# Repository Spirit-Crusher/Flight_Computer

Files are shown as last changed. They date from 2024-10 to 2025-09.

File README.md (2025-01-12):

MCU: https://www.microchip.com/en-us/product/pic32mz2048efh100

GPS: https://pt.mouser.com/ProductDetail/u-blox/NEO-M8J?qs=sGAEpiMZZMu3sxpa5v1qrlhWywTP0pnuh%2BmP8LamgMg%3D

Data logging for GPS: https://pt.mouser.com/ProductDetail/Microchip-Technology/SST26VF032BT-104I-SM?qs=wzzOUr4NhYqzScXXOX3HBA%3D%3D

IMU (acel + gyro): https://pt.mouser.com/ProductDetail/STMicroelectronics/LSM6DS3TR-C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

Magnetómetro: https://pt.mouser.com/ProductDetail/STMicroelectronics/LIS3MDLTR?qs=hnsWAVXnr6EbLE48dGN9Pg%3D%3D

Altímetro (temp incluída): https://pt.mouser.com/ProductDetail/Measurement-Specialties/MS560702BA03-50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

Buzzer: https://www.digikey.com/en/products/detail/ole-wolff-electronics-inc/OWMB-858540SA-40-15/16735155

Antena(GPS): ???

Telemetry transmiter/antenna: ???

Data logging (flash memory IC): https://pt.mouser.com/ProductDetail/Winbond/W25Q128JVSIQ?qs=qSfuJ%252Bfl%2Fd6tLXvPR4fl9w%3D%3D

Power management IC: https://pt.mouser.com/ProductDetail/Texas-Instruments/INA219BIDR?qs=1WmUhT%2FVMINyGsXNJcdD5Q%3D%3D (maybe BMS board would be better)

Pyro channels and others

Ver redundância 

# DONE
- [x] Decoupling capacitors for each IC and basic conections.
- [ ] Sorting out power (all 3V3 or anything else needed?)
- [ ] Reverse polarity protection (which approach should I use?)
- [x] Programmer pins connector

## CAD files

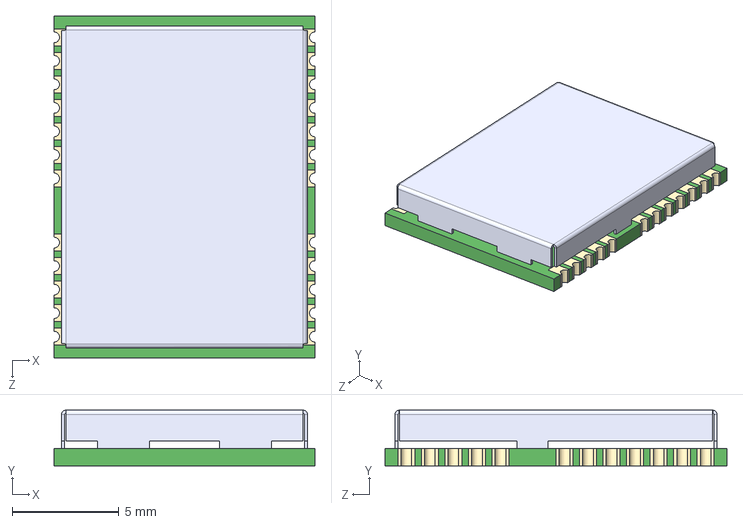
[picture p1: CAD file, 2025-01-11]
GPS_NEO-M8J/NEO-M8Q/NEO-8Q-0.STEP
12.2 x 2.60 x 16.0 mm

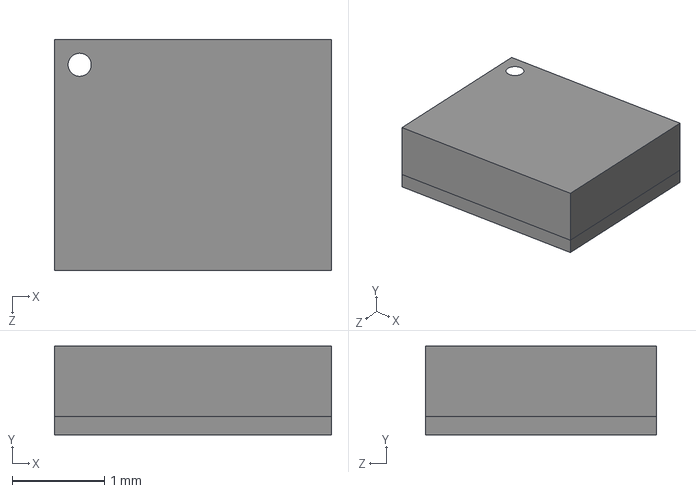
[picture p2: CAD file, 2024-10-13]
IMU_LSM6DS3TR-C/LSM6DS3TR-C.step
3.00 x 0.96 x 2.50 mm

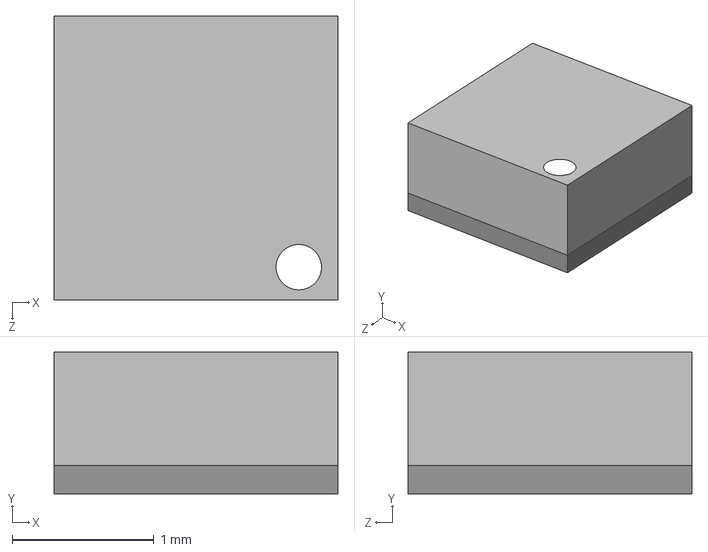
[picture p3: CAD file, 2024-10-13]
MAG_LIS3MDLTR/LIS3MDLTR.step
2.00 x 1.00 x 2.00 mm

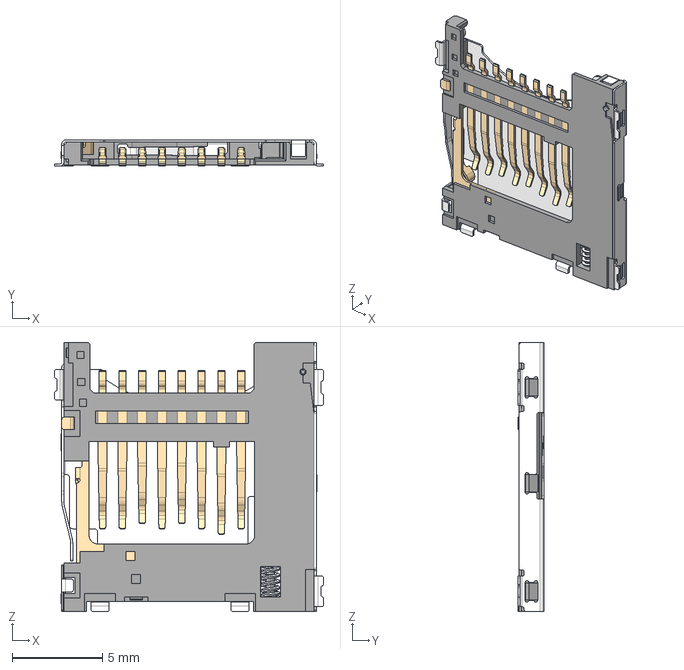
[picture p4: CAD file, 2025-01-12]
MICRO_SD/MEM2090-00-145-00-A_REVA/MEM2090-00-145-00-A_REVA.step
14.9 x 1.45 x 15.0 mm

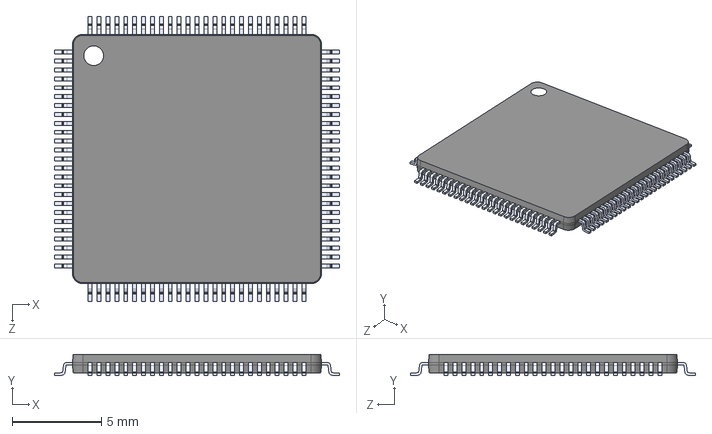
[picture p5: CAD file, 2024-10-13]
PIC32MZ2048EFH100-E_PF/PIC32MZ2048EFH100-E_PF.step
16.0 x 1.20 x 16.0 mm

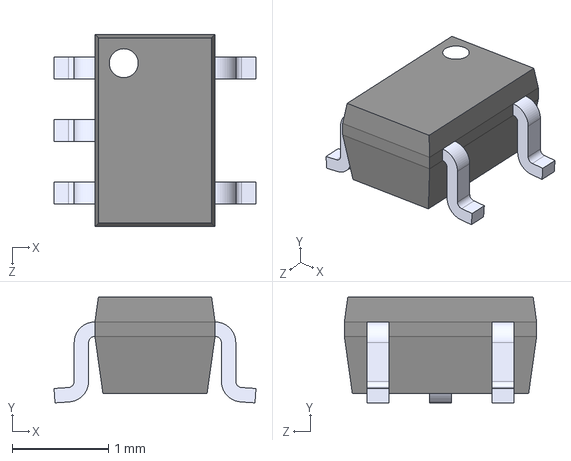
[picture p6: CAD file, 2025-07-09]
SN74AHCT1G125DCKR level shifter/SN74AHCT1G125DCKR.step
2.10 x 1.10 x 2.00 mm

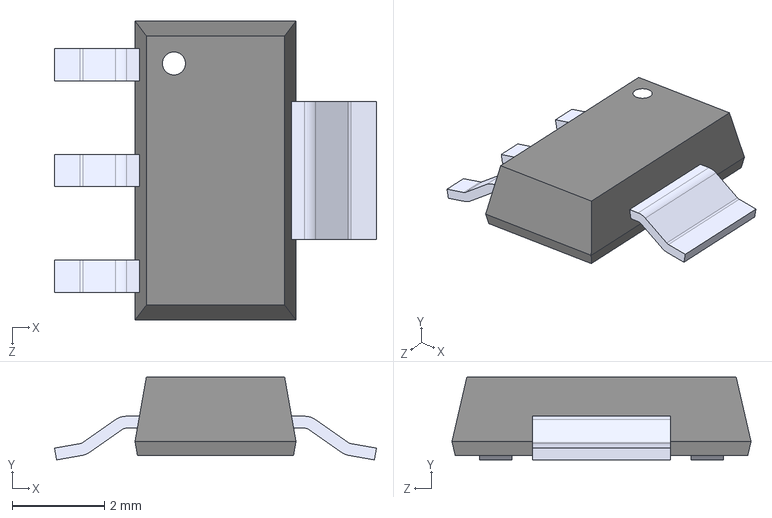
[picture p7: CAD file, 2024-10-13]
Voltage regulation/LDL1117S33R/LDL1117S33R.step
7.00 x 1.80 x 6.50 mm

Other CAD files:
Voltage regulation/LM7805MPX_NOPB/LM7805MPX_NOPB.step

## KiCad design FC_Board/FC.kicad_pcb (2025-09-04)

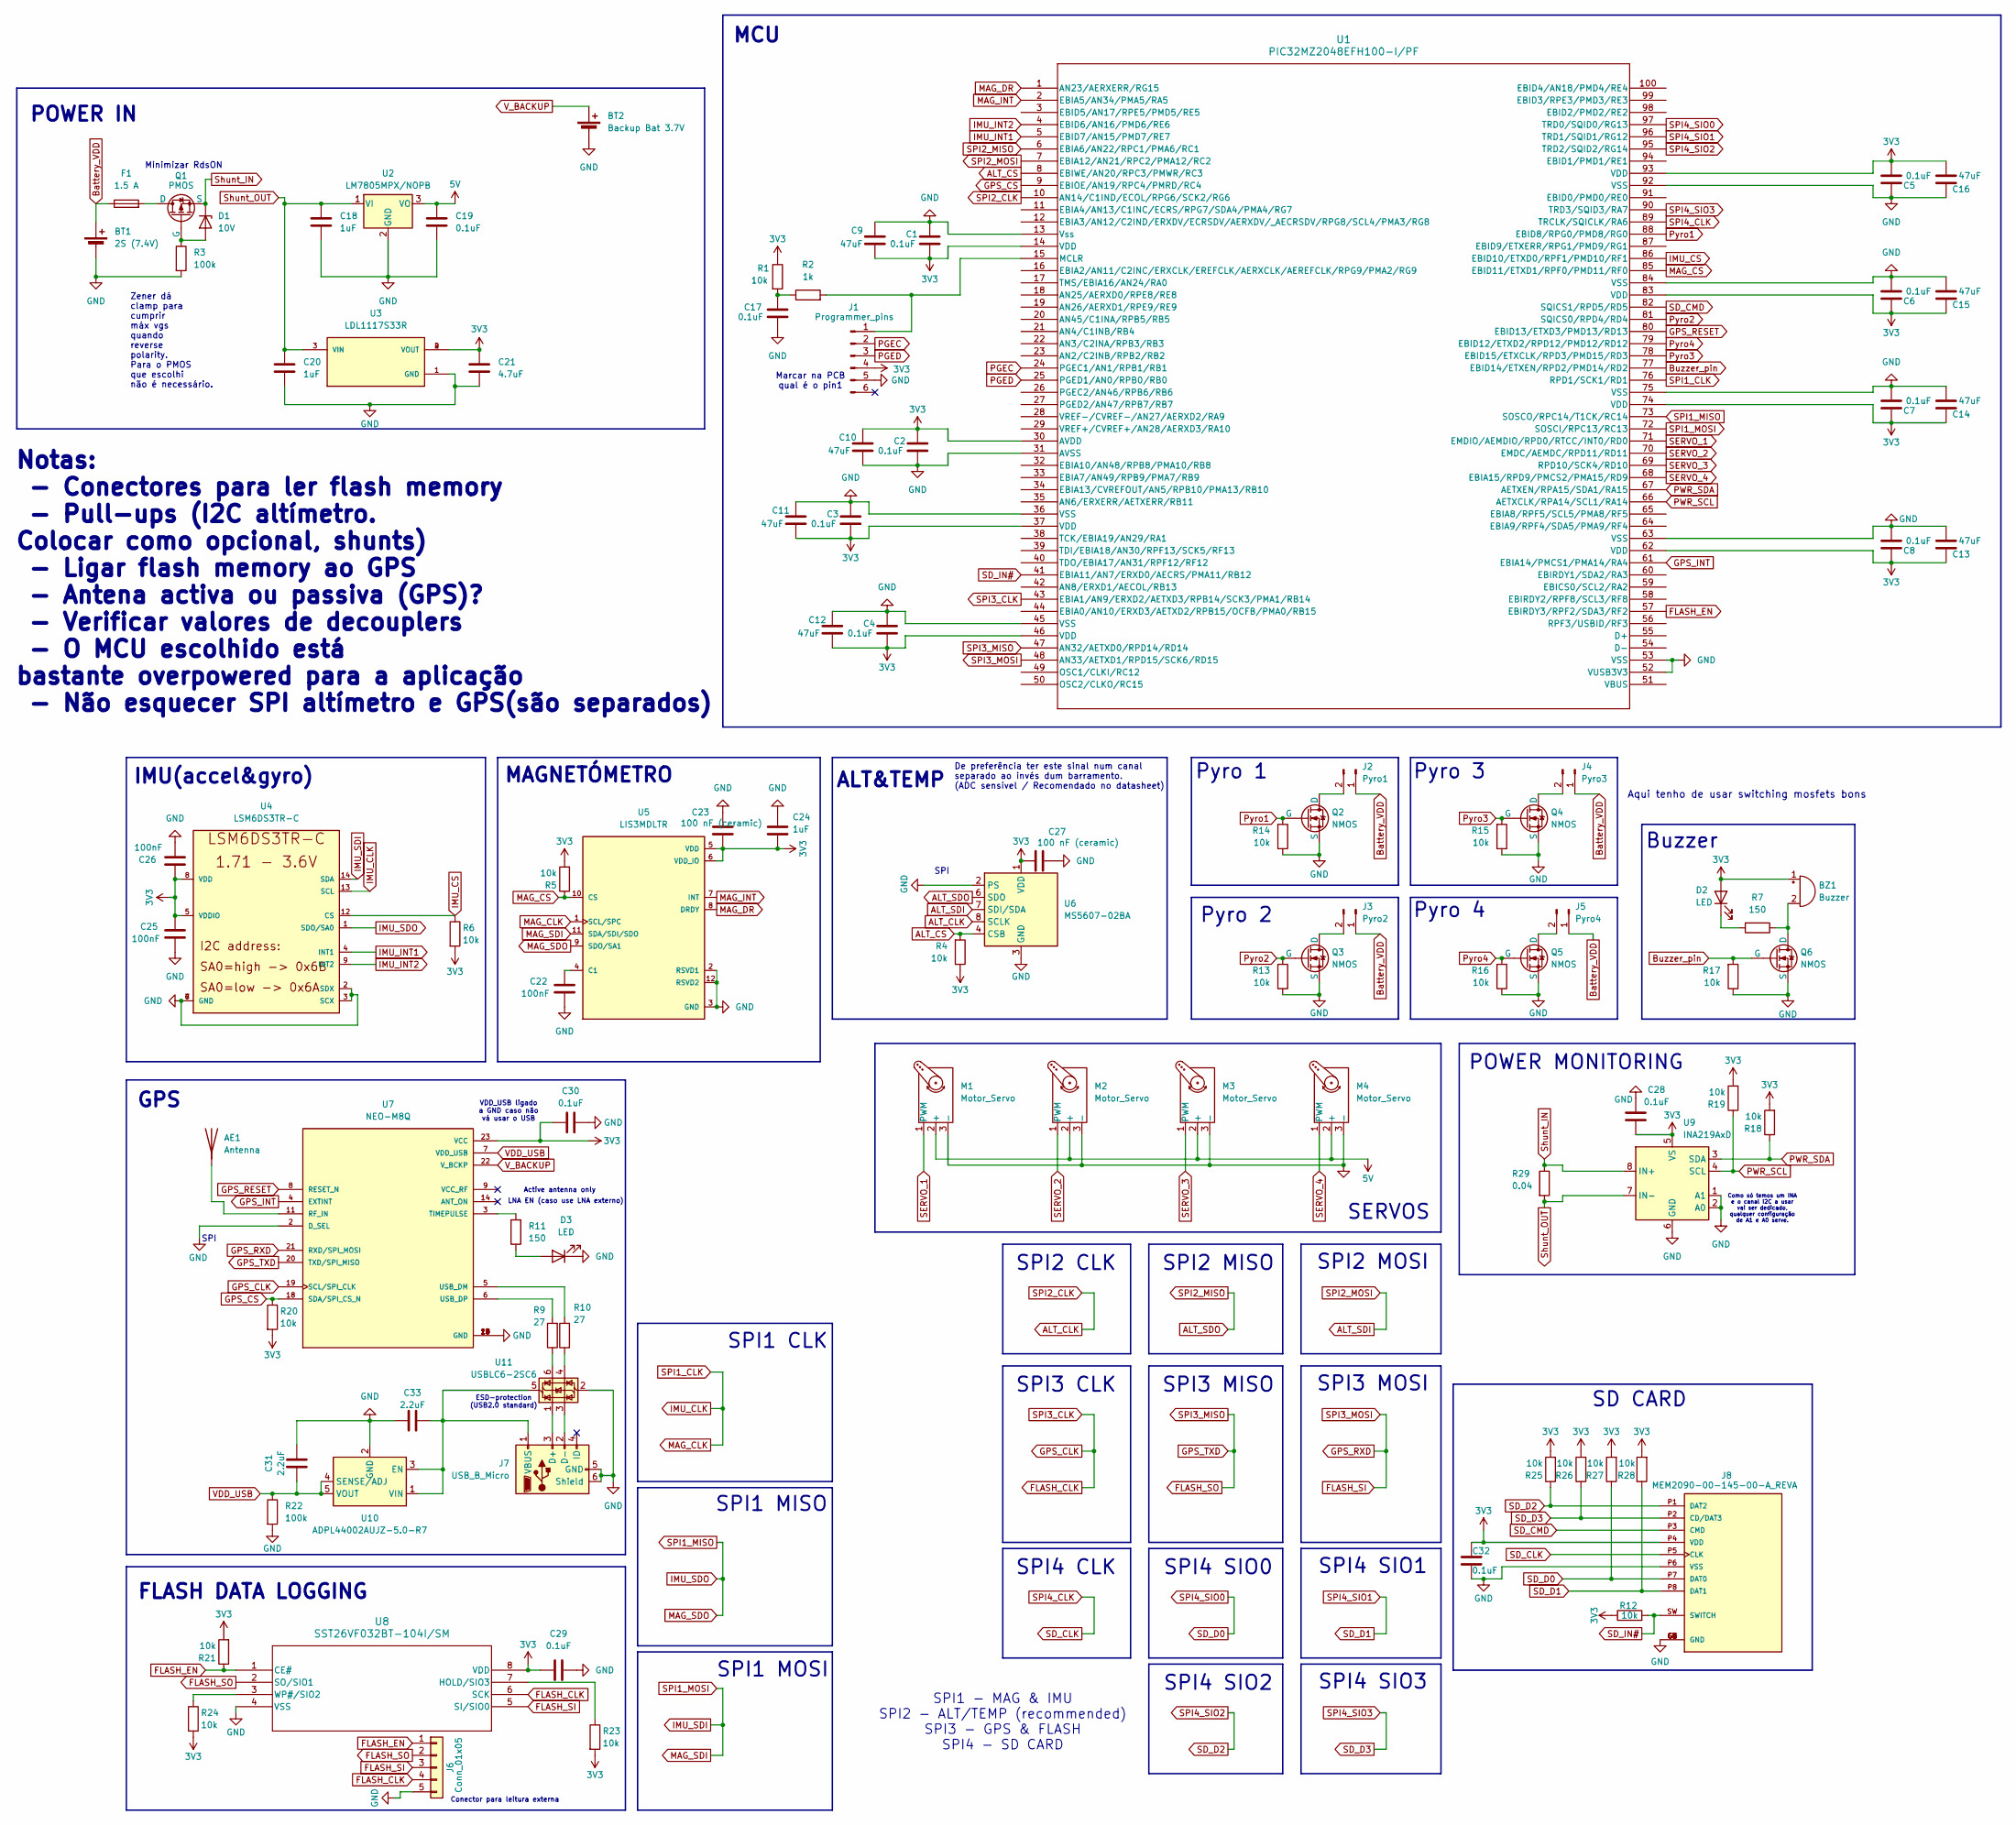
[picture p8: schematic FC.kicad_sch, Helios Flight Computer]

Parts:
AE1: Antenna; SMA_Samtec_SMA-J-P-H-ST-EM1_EdgeMount
BT1: 2S (7.4V); AMASS_XT60-M_1x02_P7.20mm_Vertical
BT2: Backup Bat 3.7V; JST_EH_B2B-EH-A_1x02_P2.50mm_Vertical
BZ1: Buzzer; Buzzer_12x9.5RM7.6
C1, C2, C3, C4, C5, C6, C7, C8, C17, C19, C28, C29, C30, C32: 0.1uF; C_0603_1608Metric_Pad1.08x0.95mm_HandSolder
C9, C10, C11, C12, C13, C14, C15, C16: 47uF; C_1210_3225Metric_Pad1.33x2.70mm_HandSolder
C18, C20, C24: 1uF; C_0603_1608Metric_Pad1.08x0.95mm_HandSolder
C21: 4.7uF; C_0805_2012Metric_Pad1.18x1.45mm_HandSolder
C22, C25, C26: 100nF; C_0603_1608Metric_Pad1.08x0.95mm_HandSolder
C23, C27: 100 nF (ceramic); C_0603_1608Metric_Pad1.08x0.95mm_HandSolder
C31, C33: 2.2uF; C_0603_1608Metric_Pad1.08x0.95mm_HandSolder
D1: 10V; D_SOD-323_HandSoldering
D2, D3: LED; LED_D3.0mm
F1: 1.5 A; Fuseholder_Cylinder-5x20mm_Schurter_0031_8201_Horizontal_Op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
J1: Programmer_pins; PinHeader_1x06_P2.54mm_Horizontal
J2: Pyro1; Molex_KK-254_AE-6410-02A_1x02_P2.54mm_Vertical
J3: Pyro2; Molex_KK-254_AE-6410-02A_1x02_P2.54mm_Vertical
J4: Pyro3; Molex_KK-254_AE-6410-02A_1x02_P2.54mm_Vertical
J5: Pyro4; Molex_KK-254_AE-6410-02A_1x02_P2.54mm_Vertical
J6: Conn_01x05; PinHeader_1x05_P2.54mm_Vertical
J7: USB_B_Micro; USB_Micro-B_Molex-105017-0001
J8: MEM2090-00-145-00-A_REVA; GCT_MEM2090-00-145-00-A_REVA; PARTREV A
M1, M2, M3, M4: Motor_Servo; Molex_KK-254_AE-6410-03A_1x03_P2.54mm_Vertical
Q1: PMOS; SOT-23-3
Q2, Q3, Q4, Q5, Q6: NMOS; SOT-23
R1, R4, R5, R6, R12, R13, R14, R15, R16, R17, R18, R19, R20, R21, R23, R24, R25, R26, R27, R28: 10k; R_0805_2012Metric_Pad1.20x1.40mm_HandSolder
R2: 1k; R_0805_2012Metric_Pad1.20x1.40mm_HandSolder
R3, R22: 100k; R_1206_3216Metric_Pad1.30x1.75mm_HandSolder
R7, R11: 150; R_0603_1608Metric_Pad0.98x0.95mm_HandSolder
R9, R10: 27; R_0603_1608Metric_Pad0.98x0.95mm_HandSolder
R29: 0.04; R_2512_6332Metric_Pad1.40x3.35mm_HandSolder
U1: PIC32MZ2048EFH100-I/PF; QFP50P1600X1600X120-100N
U2: LM7805MPX/NOPB; TO-220-3_Vertical
U3: LDL1117S33R; SOT230P700X180-4N; PARTREV 7
U4: LSM6DS3TR-C; LGA-14-2.5X3MM
U5: LIS3MDLTR; XDCR_LIS3MDLTR; PARTREV 6
U6: MS5607-02BA; LGA-8_3x5mm_P1.25mm
U7: NEO-M8Q; XCVR_NEO-M8Q; PARTREV 10
U8: SST26VF032BT-104I/SM; SOIC-8W_5.3x5.3mm_P1.27mm
U9: INA219AxD; SOIC-8_3.9x4.9mm_P1.27mm
U10: ADPL44002AUJZ-5.0-R7; TSOT-23-5
U11: USBLC6-2SC6; SOT-23-6

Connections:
3V3: BZ1.1 (+), C1.2, C2.1, C3.2, C4.2, C5.2, C6.1, C7.1, C8.1, C9.2, C10.1, C11.2, C12.2, C13.1, C14.1, C15.1, C16.2, C21.1, C23.2, C24.2, C25.1, C26.1, C27.2, C28.1, C29.2, C30.2, C32.1, D2.2 (A), J1.4, J8.P4 (VDD), R1.1, R4.1, R5.2, R6.2, R12.1, R18.2, R19.2, R20.2, R21.2, R23.2, R24.2, R25.2, R26.2, R27.2, R28.2, U1.14 (VDD), U1.30 (AVDD), U1.37 (VDD), U1.46 (VDD), U1.62 (VDD), U1.74 (VDD), U1.83 (VDD), U1.93 (VDD), U3.2 (VOUT), U3.4 (VOUT), U4.5 (VDDIO), U4.8 (VDD), U5.5 (VDD), U5.6 (VDD_IO), U6.1 (VDD), U7.23 (VCC), U8.8 (VDD), U9.5 (VS)
5V: C19.1, M1.2 (+), M2.2 (+), M3.2 (+), M4.2 (+), U2.3 (VO)
ALT_CLK: U1.10 (AN14/C1IND/ECOL/RPG6/SCK2/RG6), U6.8 (SCLK)
ALT_CS: R4.2, U1.8 (EBIWE/AN20/RPC3/PMWR/RC3), U6.4 (CSB), U6.5 (CSB)
ALT_SDI: U1.7 (EBIA12/AN21/RPC2/PMA12/RC2), U6.7 (SDI/SDA)
ALT_SDO: U1.6 (EBIA6/AN22/RPC1/PMA6/RC1), U6.6 (SDO)
Battery_VDD: BT1.1 (+), F1.1, J2.1, J3.1, J4.1, J5.1
Buzzer_pin: Q6.2 (G), R17.2, U1.77 (EBID14/ETXEN/RPD2/PMD14/RD2)
FLASH_CLK: J6.4, U1.43 (EBIA1/AN9/ERXD2/AETXD3/RPB14/SCK3/PMA1/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), U7.19 (SCL/SPI_CLK), U8.6 (SCK)
FLASH_EN: J6.1, R21.1, U1.57 (EBIRDY3/RPF2/SDA3/RF2), U8.1 (CE#)
FLASH_SI: J6.3, U1.48 (AN33/AETXD1/RPD15/SCK6/RD15), U7.21 (RXD/SPI_MOSI), U8.5 (SI/SIO0)
FLASH_SO: J6.2, U1.47 (AN32/AETXD0/RPD14/RD14), U7.20 (TXD/SPI_MISO), U8.2 (SO/SIO1)
GND: BT1.2 (-), BT2.2 (-), C1.1, C2.2, C3.1, C4.1, C5.1, C6.2, C7.2, C8.2, C9.1, C10.2, C11.1, C12.1, C13.2, C14.2, C15.2, C16.1, C17.2, C18.2, C19.2, C20.2, C21.2, C22.2, C23.1, C24.1, C25.2, C26.2, C27.1, C28.2, C29.1, C30.1, C31.2, C32.2, C33.1, D3.1 (K), J1.5, J6.5, J7.5 (GND), J7.6 (Shield), J8.G1 (GND), J8.G2 (GND), J8.G3 (GND), J8.G4 (GND), J8.G5 (GND), J8.G6 (GND), J8.P6 (VSS), M1.3 (-), M2.3 (-), M3.3 (-), M4.3 (-), Q2.3 (S), Q3.3 (S), Q4.3 (S), Q5.3 (S), Q6.3 (S), R3.2, R13.1, R14.1, R15.1, R16.1, R17.1, R22.2, U1.13 (Vss), U1.31 (AVSS), U1.36 (VSS), U1.45 (VSS), U1.52 (VUSB3V3), U1.53 (VSS), U1.63 (VSS), U1.75 (VSS), U1.84 (VSS), U1.92 (VSS), U2.2 (GND), U3.1 (GND), U4.2 (SDX), U4.3 (SCX), U4.6 (GND), U4.7 (GND), U5.2 (RSVD1), U5.3 (GND), U5.12 (RSVD2), U6.2 (PS), U6.3 (GND), U7.2 (D_SEL), U7.10 (GND), U7.12 (GND), U7.13 (GND), U7.24 (GND), U8.4 (VSS), U9.1 (A1), U9.2 (A0), U9.6 (GND), U10.2 (GND), U11.2 (GND)
GPS_CS: R20.1, U1.9 (EBIOE/AN19/RPC4/PMRD/RC4), U7.18 (SDA/SPI_CS_N)
GPS_INT: U1.61 (EBIA14/PMCS1/PMA14/RA4), U7.4 (EXTINT)
GPS_RESET: U1.80 (EBID13/ETXD3/PMD13/RD13), U7.8 (RESET_N)
IMU_CLK: U1.76 (RPD1/SCK1/RD1), U4.13 (SCL), U5.1 (SCL/SPC)
IMU_CS: R6.1, U1.86 (EBID10/ETXD0/RPF1/PMD10/RF1), U4.12 (CS)
IMU_INT1: U1.5 (EBID7/AN15/PMD7/RE7), U4.4 (INT1)
IMU_INT2: U1.4 (EBID6/AN16/PMD6/RE6), U4.9 (INT2)
IMU_SDI: U1.72 (SOSCI/RPC13/RC13), U4.14 (SDA), U5.11 (SDA/SDI/SDO)
IMU_SDO: U1.73 (SOSCO/RPC14/T1CK/RC14), U4.1 (SDO/SA0), U5.9 (SDO/SA1)
MAG_CS: R5.1, U1.85 (EBID11/ETXD1/RPF0/PMD11/RF0), U5.10 (CS)
MAG_DR: U1.1 (AN23/AERXERR/RG15), U5.8 (DRDY)
MAG_INT: U1.2 (EBIA5/AN34/PMA5/RA5), U5.7 (INT)
unnamed: AE1.1 (A), U7.11 (RF_IN)
unnamed: BZ1.2 (-), Q6.1 (D), R7.1
unnamed: C17.1, R1.2, R2.1
unnamed: D1.2 (A), Q1.2 (G), R3.1
unnamed: D2.1 (K), R7.2
unnamed: D3.2 (A), R11.1
unnamed: J1.1, R2.2, U1.15 (MCLR)
unnamed: J2.2, Q2.1 (D)
unnamed: J3.2, Q3.1 (D)
unnamed: J4.2, Q4.1 (D)
unnamed: J5.2, Q5.1 (D)
unnamed: J7.3 (D+), U11.1 (I/O1)
unnamed: J7.2 (D-), U11.3 (I/O2)
unnamed: C33.2, J7.1 (VBUS), U10.1 (VIN), U10.3 (EN), U11.5 (VBUS)
unnamed: F1.2, Q1.1 (D)
unnamed: R9.1, U11.6 (I/O1)
unnamed: R10.1, U11.4 (I/O2)
unnamed: C22.1, U5.4 (C1)
unnamed: R11.2, U7.3 (TIMEPULSE)
unnamed: R10.2, U7.5 (USB_DM)
unnamed: R9.2, U7.6 (USB_DP)
unnamed: R23.1, U8.7 (HOLD/SIO3)
unnamed: R24.1, U8.3 (WP#/SIO2)
PGEC: J1.2, U1.24 (PGEC1/AN1/RPB1/RB1)
PGED: J1.3, U1.25 (PGED1/AN0/RPB0/RB0)
PWR_SCL: R19.1, U1.66 (AETXCLK/RPA14/SCL1/RA14), U9.4 (SCL)
PWR_SDA: R18.1, U1.67 (AETXEN/RPA15/SDA1/RA15), U9.3 (SDA)
Pyro1: Q2.2 (G), R14.2, U1.88 (EBID8/RPG0/PMD8/RG0)
Pyro2: Q3.2 (G), R13.2, U1.81 (SQICS0/RPD4/RD4)
Pyro3: Q4.2 (G), R15.2, U1.78 (EBID15/ETXCLK/RPD3/PMD15/RD3)
Pyro4: Q5.2 (G), R16.2, U1.79 (EBID12/ETXD2/RPD12/PMD12/RD12)
SD_CLK: J8.P5 (CLK), U1.89 (TRCLK/SQICLK/RA6)
SD_CMD: J8.P3 (CMD), U1.82 (SQICS1/RPD5/RD5)
SD_D0: J8.P7 (DAT0), R27.1, U1.97 (TRD0/SQID0/RG13)
SD_D1: J8.P8 (DAT1), R28.1, U1.96 (TRD1/SQID1/RG12)
SD_D2: J8.P1 (DAT2), R25.1, U1.95 (TRD2/SQID2/RG14)
SD_D3: J8.P2 (CD/DAT3), R26.1, U1.90 (TRD3/SQID3/RA7)
SD_IN#: J8.SW (SWITCH), R12.2, U1.41 (EBIA11/AN7/ERXD0/AECRS/PMA11/RB12)
SERVO_1: M1.1 (PWM), U1.71 (EMDIO/AEMDIO/RPD0/RTCC/INT0/RD0)
SERVO_2: M2.1 (PWM), U1.70 (EMDC/AEMDC/RPD11/RD11)
SERVO_3: M3.1 (PWM), U1.69 (RPD10/SCK4/RD10)
SERVO_4: M4.1 (PWM), U1.68 (EBIA15/RPD9/PMCS2/PMA15/RD9)
Shunt_IN: D1.1 (K), Q1.3 (S), R29.1, U9.8 (IN+)
Shunt_OUT: C18.1, C20.1, R29.2, U2.1 (VI), U3.3 (VIN), U9.7 (IN-)
VDD_USB: C31.1, R22.1, U7.7 (VDD_USB), U10.4 (SENSE/ADJ), U10.5 (VOUT)
V_BACKUP: BT2.1 (+), U7.22 (V_BCKP)

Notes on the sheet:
Pyro 3
SPI3 CLK
SPI
MAGNETÓMETRO
Buzzer
FLASH DATA LOGGING
Aqui tenho de usar switching mosfets bons
SPI2 MOSI
Notas: - Conectores para ler flash memory - Pull-ups (I2C altímetro. Colocar como opcional, shunts) - Ligar flash memory ao GPS - Antena activa ou passiva (GPS)? - Verificar valores de decouplers - O MCU escolhido está bastante overpowered para a aplicação - Não esquecer SPI altímetro e GPS(são sep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
GPS
Pyro 2
IMU(accel&gyro)
SPI3 MISO
SPI1 MOSI
SERVOS
SPI1 - MAG & IMU SPI2 - ALT/TEMP (recommended) SPI3 - GPS & FLASH SPI4 - SD CARD
Zener dá clamp para cumprir máx vgs quando reverse polarity. Para o PMOS que escolhi não é necessário.
VDD_USB ligado a GND caso não vá usar o USB
Pyro 1
De preferência ter este sinal num canal separado ao invés dum barramento. (ADC sensível / Recomendado no datasheet)
ALT&TEMP
Minimizar RdsON
SD CARD
SPI1 MISO
Como só temos um INA e o canal I2C a usar vai ser dedicado, qualquer configuração de A1 e A0 serve.
SPI2 MISO
ESD-protection (USB2.0 standard)
Conector para leitura externa
Marcar na PCB qual é o pin1
SPI4 SIO0
SPI4 SIO3
SPI2 CLK
SPI4 SIO1
POWER MONITORING
Pyro 4
SPI4 CLK
LNA EN (caso use LNA externo)
MCU
Active antenna only
SPI1 CLK

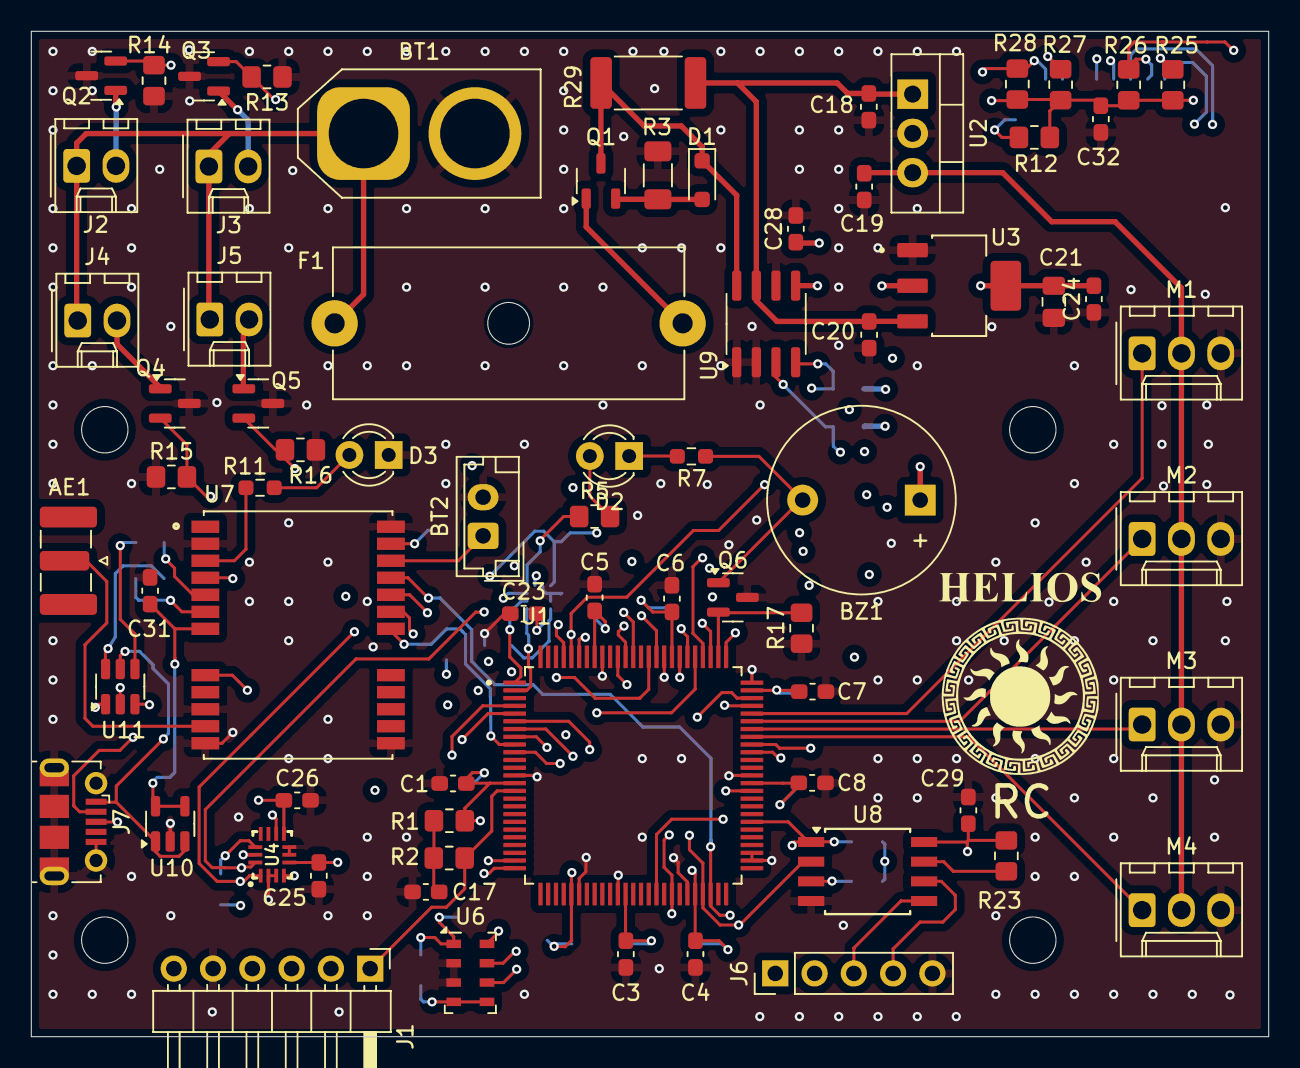
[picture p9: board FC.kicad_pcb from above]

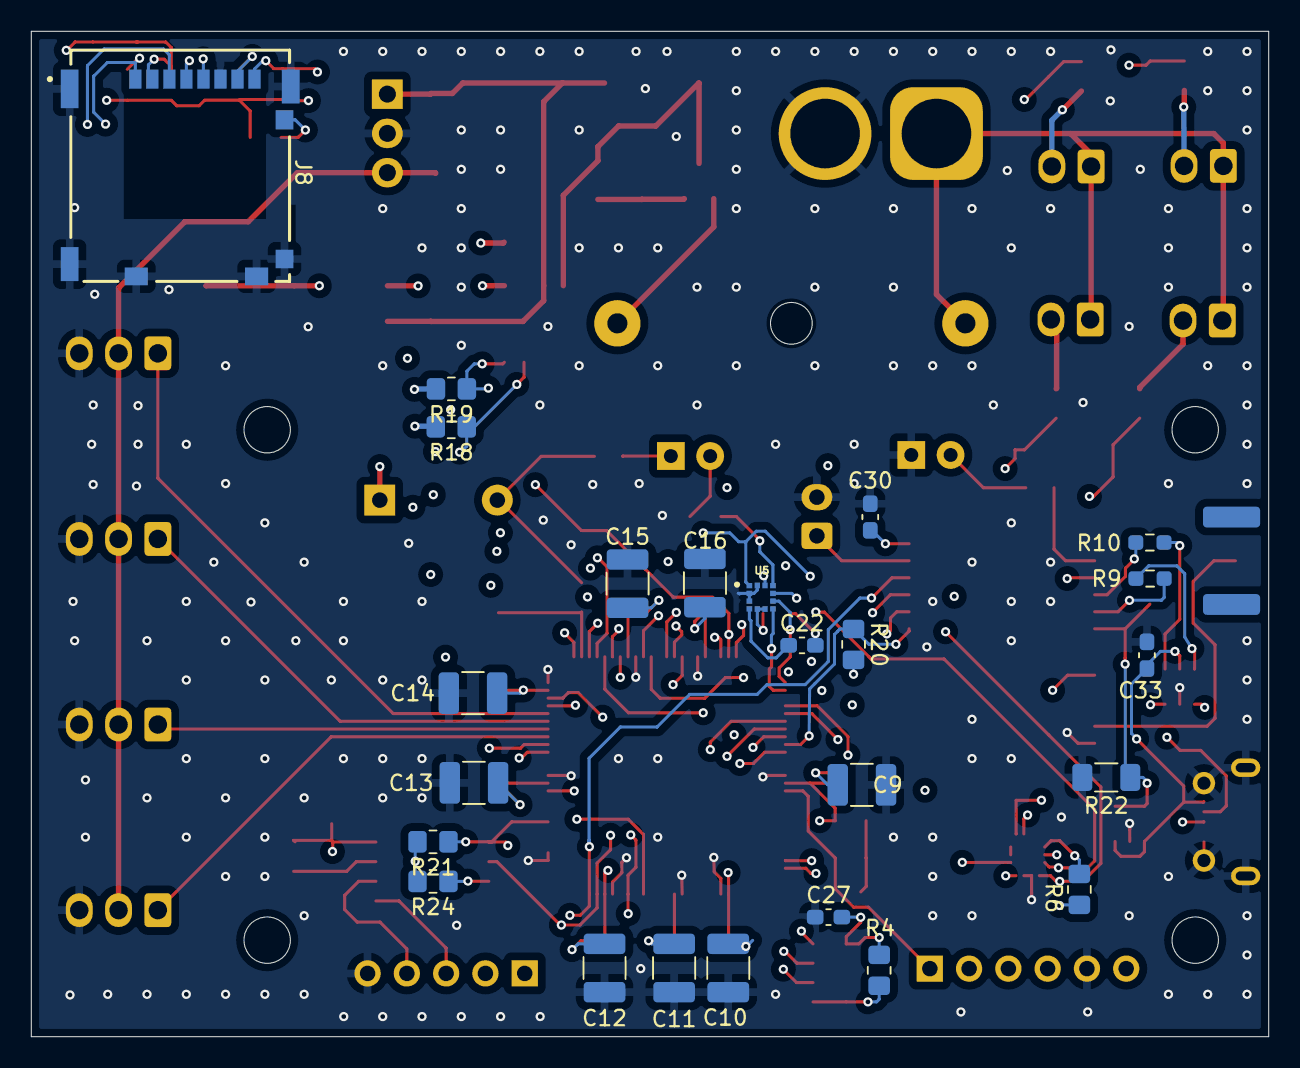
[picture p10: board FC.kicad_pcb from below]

Board: 4 copper layers, 80.0 x 65.0 mm, 97 parts (24 on the bottom side), 71 nets.

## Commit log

2024-10-13 Added datasheets and footprints/symbols
    [FC.kicad_sch, LIS3MDLTR.step, LSM6DS3TR-C.step]
2024-10-15 Added IC decoupling and basic connections
    [FC.kicad_sch]
2025-01-11 Schematic progress
    GPS data logging, Power monitoring and other updates to schematic.
    [FC.kicad_sch, NEO-8Q-0.STEP]
2025-01-12 Added SD card and some other basic stuff
    [FC.kicad_sch, MEM2090-00-145-00-A_REVA.step]
2025-07-09 Schematic update
    - Add: PWM level shifting
    - Add: SPI bus
    - Add: buzzer drain setup
    - Update: 5V power for servos
    - Verify: LDO sizing
    [FC.kicad_sch, SN74AHCT1G125DCKR.step]
2025-07-10 Schematic update
    - Remove: Buffers on PWM unnecessary (internal servo logic handles 3V3)
    - Add: Selecting PIC pins for SPI bus and sensor interrupts
    - Other minor tweaks
    [FC.kicad_sch]
2025-07-12 Power monitoring done
    [FC.kicad_sch]
2025-07-12 Schematic update
    - Add: SPI2 channel
    - Add: INA I2C connections
    - Component selection
    [FC.kicad_sch]
2025-07-12 Schematic update
    - Add: GPS USB and UART
    - Add: USB 2.0 standard related circuitry
    - Finished third SPI Bus
    - Started Quad SPI Bus for data logging (SD card and Flash)
    [FC.kicad_sch]
2025-07-13 Schematic Done
    [FC.kicad_pcb, FC.kicad_sch]
2025-07-14 Started PCB
    [FC.kicad_pcb, FC.kicad_sch]
2025-07-14 First placement attempt
    [FC.kicad_pcb, FC.kicad_sch]
2025-07-14 Transitioning to 4 layers
    Tried 2 layer routing to minimize cost. Too many tracks...
    [FC.kicad_pcb, FC.kicad_sch]
2025-08-18 Routing done except for gnd vias
    [FC.kicad_pcb]
2025-09-04 Helios_v1.0 DONE
    [FC.kicad_pcb]
